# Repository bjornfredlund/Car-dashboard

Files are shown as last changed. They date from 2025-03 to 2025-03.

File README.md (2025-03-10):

# Custom ESP32-Based PCB with Bluetooth & Sensor Integration

## Overview

Custom PCB built around the **ESP32** microcontroller. The board integrates multiple sensors and modules, making it suitable for applications such as **data logging, motion tracking, FM transmission, and GNSS-based navigation**. Sample project using the [board](https://github.com/bjornfredlund/ESP32-Car-Dashboard) as a Car dashboard/telemetry unit, providing positiong, velocity, acceleration and bluetooth transmitting capabilities.

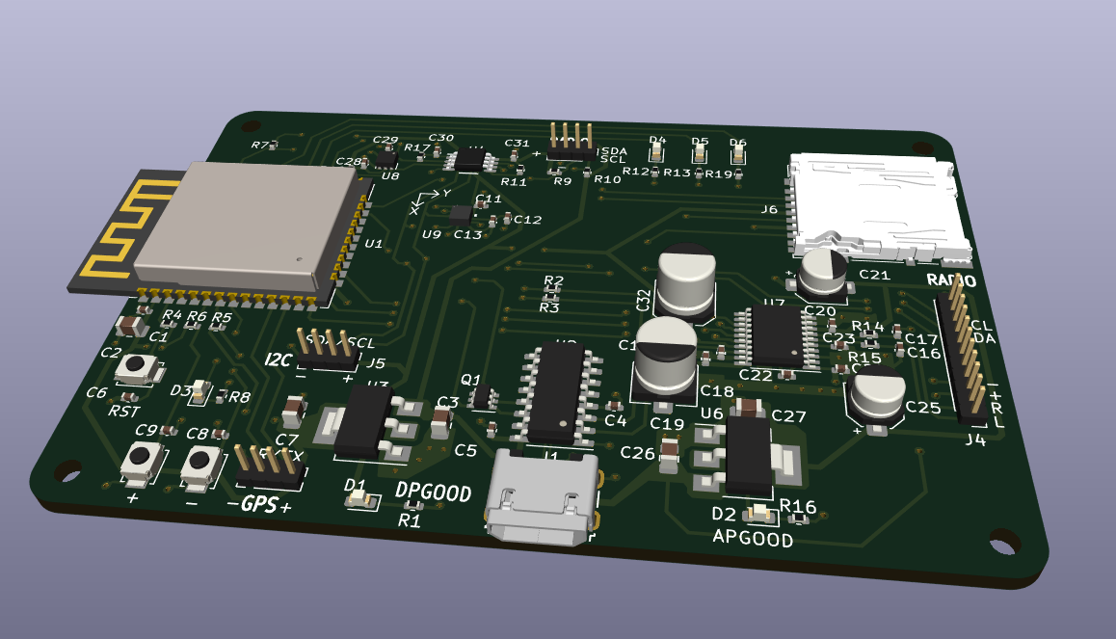
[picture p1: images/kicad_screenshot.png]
Kicad screenshot


## Features
- **ESP32-WROOM-E**
- **TMP117AIDRVR Temperature Sensor**
- **MicroSD Card Reader**
- **TCA9517DGKRQ1 Level shifter for 5v I2C communication** 
- **PCM5102 DAC for Audio Processing**
- **I2C bus to FM Radio Transmitter**
- **LIS2DH12TR Accelerometer**
- **GNSS Receiver via UART**
- **3 User-Programmable Buttons**
## Requirements

- **ESP-IDF v5.3** – Required for firmware development and deployment.

## Applications

- **Wireless Sensor Hub** – Collect and transmit sensor data over Bluetooth.
- **Portable FM Transmitter** – Stream audio to nearby FM receivers.
- **Data Logger** – Store sensor data on an SD card for later analysis.
- **Motion & Position Tracking** – Use accelerometer and GNSS for movement-based applications.

## Getting Started

### 1. **Hardware Setup**

- Power the PCB via **USB or an external battery**.
- Connect necessary peripherals (antennas, audio sources, etc.).

### 2. **Firmware Development**

- Use the **ESP-IDF** or **Arduino IDE** to program the ESP32.
- Implement communication with the sensors and peripherals via **I2C, UART, and SPI**.

### 3. I2C Device addresses 
    TMP117AIDRVR: 0x48
    PCM5102: 0xC0
    LIS2DH12TR: 0x19

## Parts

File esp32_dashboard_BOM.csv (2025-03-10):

Id | Designator | Footprint | Quantity | Designation | Manufacturer | Mfg part
1 | U9 | LGA-12_STM | 1 | LIS2DH12TR | STMicroelectronics | LIS2DUX12TR
2 | C13,C11,C30,C29,C5,C28,C4,C31,C6 | C_0402_1005Metric | 9 | 100nF | Murata Electronics | GMD155R71C104KA11D
3 | C12 | C_0402_1005Metric | 1 | 10uF | KYOCERA AVX | CM05X5R106M10AH
4 | C21,C25 | CP_Elec_4x3 | 2 | 10uF | Wurth Elektronik | 865060643005
5 | J2,J5,J3 | PinHeader_1x04_P1.27mm_Vertical | 3 | Conn_01x04_Pin | SAMTEC | SAM1029-04-ND
6 | D1,D5,D2,D6,D4,D3 | LED_0603_1608Metric | 6 | GREEN | VISHAY | TLMP1100-GS08
7 | R10,R9,R7,R18,R17 | R_0402_1005Metric | 5 | 4k7 | YAGEO | RC0402JR-074K7L
8 | R2,R3 | R_0402_1005Metric | 2 | 0 | Panasonic Electronic Components | ERJ-2GE0R00X
9 | U4 | DGK0008A_N | 1 | TCA9517DGKRQ1 | Texas Instruments | TCA9517DGKRQ1
10 | J4 | PinHeader_1x11_P1.27mm_Vertical | 1 | Conn_01x11_Pin | Adam Tech | PH1-11-UA
11 | C24,C20,C2,C15,C8,C9,C18 | C_0402_1005Metric | 7 | 0.1uF | TAIYO YUDEN | MBASU105SB7104KFNA01
13 | C17,C16 | C_0402_1005Metric | 2 | 2.2nF | KEMET | C0402C222K5RACAUTO
14 | R11,R4 | R_0402_1005Metric | 2 | 10k | VISHAY | CRCW040210K0FKED
15 | J1 | USB_Micro-B_Wuerth_629105150521 | 1 | USB_B_Micro | Wurth Elektronik | 629105150521
16 | U7 | TSSOP-20_4.4x6.5mm_P0.65mm | 1 | PCM5102A | Texas Instruments | PCM5102APWR
17 | R12,R13,R8,R16,R19,R1 | R_0402_1005Metric | 6 | 1k | VISHAY | CRCW04021K00FKED
18 | C32,C19 | CP_Elec_5x5.3 | 2 | 10uF | Nichicon | UWT1E100MCL1GB
20 | U8 | WSON-6-1EP_2x2mm_P0.65mm_EP1x1.6mm | 1 | TMP117xxDRV | Texas Instruments | TMP117AIDRVR
21 | C1,C7,C27,C3,C26 | C_0805_2012Metric | 5 | 22uF | YAGEO | CC0805MKX5R7BB226
22 | SW3,SW1,SW2 | SW_SPST_B3U-1000P | 3 | SW_Push | Omron Electronics Inc-EMC Div | B3U-1000P
23 | Q1 | SOT-363_SC-70-6 | 1 | UMH3N | Jiangsu Changjing Electronics Technology Co., Ltd. | UMH3N
24 | R14,R15 | R_0402_1005Metric | 2 | 470 | VISHAY | CRCW0402470RFKED
25 | R6,R5 | R_0402_1005Metric | 2 | 1K | VISHAY | CRCW04021K00FKED.
26 | U1 | ESP32-WROOM-32E | 1 | ESP32-WROOM-E | Espressif Systems | ESP32-WROOM-32E-N16
27 | U2 | SOIC-16_3.9x9.9mm_P1.27mm | 1 | CH340C | WCH(Jiangsu Qin Heng) | CH340C
28 | J6 | microSD_HC_Hirose_DM3AT-SF-PEJM5 | 1 | Micro_SD_Card | HIROSE;DM3AT-SF-PEJM5"
29 | U6,U3 | SOT-223-3_TabPin2 | 2 | AMS1117-3.3 | UMW | AMS1117-3.3

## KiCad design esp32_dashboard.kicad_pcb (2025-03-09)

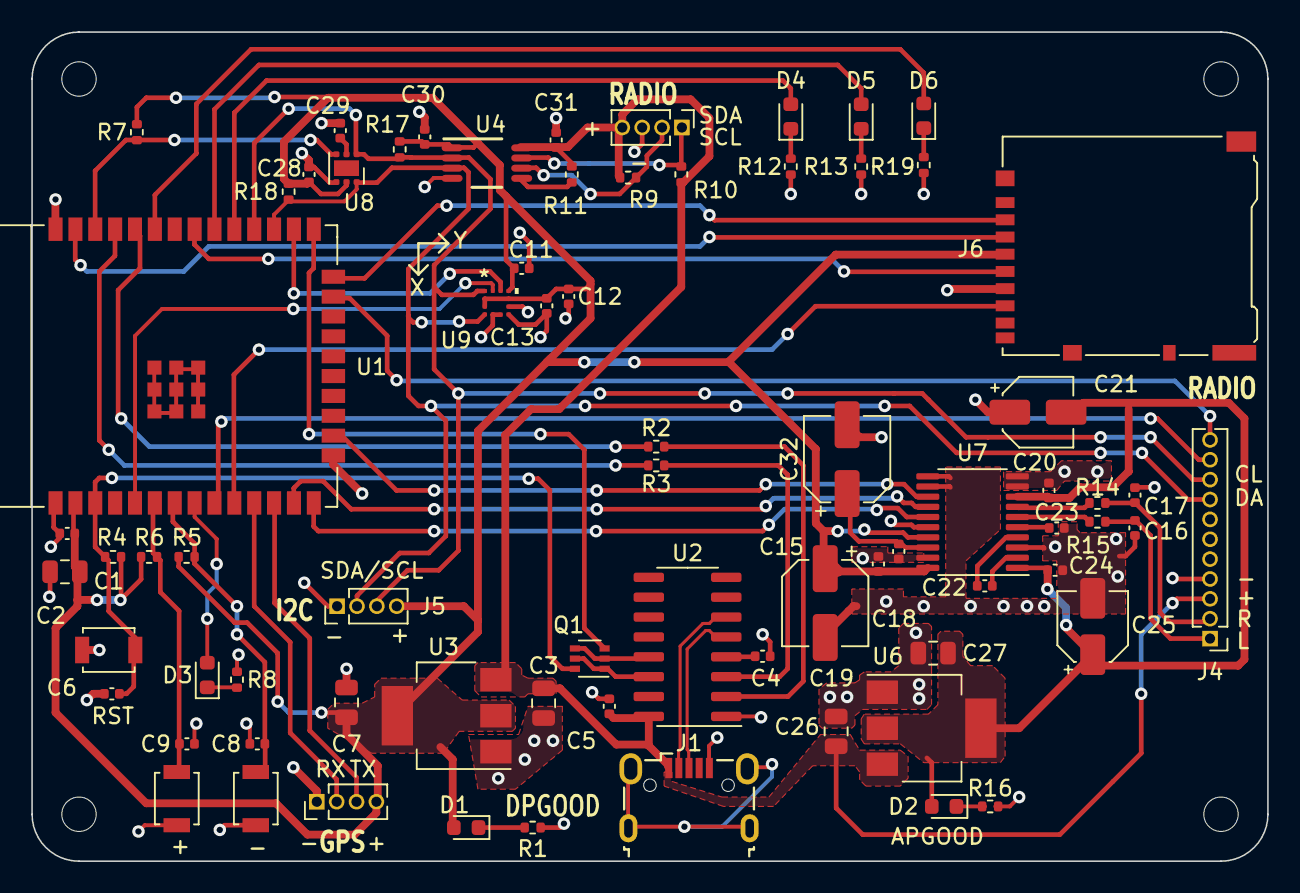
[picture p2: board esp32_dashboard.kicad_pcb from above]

Board: 2 copper layers, 79.0 x 53.0 mm, 77 parts (0 on the bottom side), 55 nets.

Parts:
C1, C3, C7, C26, C27: 22uF; C_0805_2012Metric
C2, C8, C9, C15, C18, C20, C24: 0.1uF; C_0402_1005Metric
C4, C5, C6, C11, C13, C28, C29, C30, C31: 100nF; C_0402_1005Metric
C12: 10uF; C_0402_1005Metric
C16, C17: 2.2nF; C_0402_1005Metric
C19, C32: 10uF; CP_Elec_5x5.3
C21, C25: 10uF; CP_Elec_4x3
C22, C23: 2.2uF; C_0402_1005Metric
D1, D2, D3, D4, D5, D6: RED; LED_0603_1608Metric
H1, H2, H3, H4: MountingHole; MountingHole_2.2mm_M2
J1: USB_B_Micro; USB_Micro-B_Wuerth_629105150521
J2, J3, J5: Conn_01x04_Pin; PinHeader_1x04_P1.27mm_Vertical
J4: Conn_01x11_Pin; PinHeader_1x11_P1.27mm_Vertical
J6: Micro_SD_Card; microSD_HC_Hirose_DM3AT-SF-PEJM5
Q1: UMH3N; SOT-363_SC-70-6
R1, R8, R12, R13, R16, R19: 1k; R_0402_1005Metric
R2, R3: 0; R_0402_1005Metric
R4, R11: 10k; R_0402_1005Metric
R5, R6: 1K; R_0402_1005Metric
R7, R9, R10, R17, R18: 4k7; R_0402_1005Metric
R14, R15: 470; R_0402_1005Metric
SW1, SW2, SW3: SW_Push; SW_SPST_B3U-1000P
U1: ESP32-WROOM-E; ESP32-WROOM-32E
U2: CH340C; SOIC-16_3.9x9.9mm_P1.27mm
U3, U6: AMS1117-3.3; SOT-223-3_TabPin2
U4: TCA9517DGKRQ1; DGK0008A_N
U7: PCM5102A; TSSOP-20_4.4x6.5mm_P0.65mm
U8: TMP117xxDRV; WSON-6-1EP_2x2mm_P0.65mm_EP1x1.6mm
U9: LIS2DH12TR; LGA-12_STM

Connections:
5V: C3.1, C5.1, C26.1, C31.2, J1.1 (VBUS), J2.4, J4.3, R9.1, R10.1, R11.2, U2.16 (VCC), U3.3 (VI), U4.8 (VCCB), U6.3 (VI)
+3V3: C1.1, C2.1, C7.2, C11.1, C12.1, C13.1, C15.1, C19.1, C28.1, C30.1, D1.2 (A), J3.4, J5.4, J6.4 (VDD), R4.1, R5.1, R6.1, R7.1, R17.1, R18.1, U1.2 (3V3), U3.2 (VO), U4.1 (VCCA), U7.17 (XSMT), U7.20 (DVDD), U8.5 (V+), U9.2 (CS), U9.3 (SDO/SA0), U9.9 (VDD), U9.10 (VDD_IO)
/ACC_INT1: U1.5 (SENSOR_VN/GPIO39/ADC1_CH3), U9.12 (INT1)
/ACC_INT2: U1.26 (ADC2_CH0/GPIO4), U9.11 (INT2)
/Audio/Lout: C16.1, J4.1, R14.2
/Audio/Rout: C17.1, J4.2, R15.1
/BOOT: Q1.3 (C2), U1.25 (GPIO0/BOOT/ADC2_CH1)
/BTN1: C8.1, R5.2, SW1.1, U1.7 (GPIO35/ADC1_CH7)
/BTN2: C9.1, R6.2, SW3.1, U1.6 (GPIO34/ADC1_CH6)
/DTR: Q1.2 (B1), Q1.4 (E2), U2.13 (~DTR)
/EN: C6.1, Q1.6 (C1), R4.2, SW2.1, U1.3 (EN/CHIP_PU)
/RTS: Q1.1 (E1), Q1.5 (B2), U2.14 (~RTS)
/RXD0: R2.2, U1.34 (U0RXD/GPIO3)
/RX_GPS: J3.2, U1.11 (DAC_2/ADC2_CH9/GPIO26)
/SCL5v: J2.1, R10.2, U4.7 (SCLB)
/SDA5v: J2.2, R9.2, U4.6 (SDAB)
/TXD0: R3.2, U1.35 (U0TXD/GPIO1)
/TX_GPS: J3.3, U1.12 (ADC2_CH7/GPIO27)
/T_ALERT: R7.2, U1.36 (GPIO22), U8.3 (ALERT)
/USB+: J1.3 (D+), U2.5 (UD+)
/USB-: J1.2 (D-), U2.6 (UD-)
ESP_OK: D3.2 (A), U1.8 (32K_XP/GPIO32/ADC1_CH4)
GND: C1.2, C2.2, C3.2, C4.1, C5.2, C6.2, C7.1, C8.2, C9.2, C11.2, C12.2, C13.2, C15.2, C16.2, C17.2, C18.1, C19.2, C20.2, C21.1, C23.2, C24.1, C25.2, C26.2, C27.1, C28.2, C29.2, C30.2, C31.1, C32.2, J1.5 (GND), J2.3, J3.1, J4.4, J5.1, J6.6 (VSS), R1.2, R8.2, R12.2, R13.2, R16.2, R19.2, SW1.2, SW2.2, SW3.2, U1.1 (GND), U1.15 (GND), U1.38 (GND), U2.1 (GND), U3.1 (GND), U4.4 (GND), U6.1 (GND), U7.3 (CPGND), U7.9 (AGND), U7.10 (DEMP), U7.11 (FLT), U7.12 (SCK), U7.16 (FMT), U7.19 (DGND), U8.4 (ADD0), U9.5 (RES), U9.6 (GND), U9.7 (GND), U9.8 (GND)
I2S_BCK: U1.16 (MTCK/GPIO13/ADC2_CH4), U7.13 (BCK)
I2S_DATA: U1.13 (MTMS/GPIO14/ADC2_CH6), U7.14 (DIN)
I2S_LRCK: U1.14 (MTDI/GPIO12/ADC2_CH5), U7.15 (LRCK)
LED_0: D4.2 (A), U1.29 (GPIO5)
LED_1: D5.2 (A), U1.30 (GPIO18)
LED_2: D6.2 (A), U1.33 (GPIO21)
MISO: J6.7 (DAT0), U1.10 (DAC_1/ADC2_CH8/GPIO25)
MOSI: J6.3 (CMD), U1.37 (GPIO23)
unnamed: D1.1 (K), R1.1
unnamed: D2.1 (K), R16.1
unnamed: D3.1 (K), R8.1
unnamed: D4.1 (K), R12.1
unnamed: D5.1 (K), R13.1
unnamed: D6.1 (K), R19.1
unnamed: R3.1, U2.3 (RXD)
unnamed: R2.1, U2.2 (TXD)
unnamed: C4.2, U2.4 (V3)
unnamed: R11.1, U4.5 (EN)
unnamed: C22.2, U7.4 (CAPM)
unnamed: C22.1, U7.2 (CAPP)
unnamed: C18.2, C32.1, U7.18 (LDOO)
unnamed: R14.1, U7.6 (OUTL)
unnamed: R15.2, U7.7 (OUTR)
unnamed: C23.1, U7.5 (VNEG)
unnamed: C29.1, U8.2 (GND)
SCK: J6.5 (CLK), U1.31 (GPIO19)
SCL3v3: J4.9, J5.3, R17.2, U1.28 (GPIO17), U4.2 (SCLA), U8.1 (SCL), U9.1 (SCL/SPC)
SDA3v3: J4.8, J5.2, R18.2, U1.27 (GPIO16), U4.3 (SDAA), U8.6 (SDA), U9.4 (SDA/SDI/SDO)
Si Addr: J4.10, U1.9 (32K_XN/GPIO33/ADC1_CH5)
Si RST: J4.11, U1.23 (MTDO/GPIO15/ADC2_CH3)
VDDA: C20.1, C21.2, C24.2, C25.1, C27.2, D2.2 (A), U6.2 (VO), U7.1 (CPVDD), U7.8 (AVDD)
uSD_CS: J6.2 (DAT3/CD), U1.24 (ADC2_CH2/GPIO2)

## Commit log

2025-03-09 add schematic and pcb
    [audio.kicad_sch, esp32_dashboard.kicad_pcb, esp32_dashboard.kicad_sch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]
2025-03-09 add kicad project
2025-03-10 add manufacturing BOM
    [esp32_dashboard_BOM.csv]
2025-03-10 update with i2c addresses
2025-03-10 update readme with sample project
